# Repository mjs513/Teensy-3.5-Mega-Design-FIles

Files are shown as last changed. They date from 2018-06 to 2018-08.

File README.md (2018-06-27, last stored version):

# Teensy-3.5-Mega-Design-FIles
Kicad/Gerber files for the Teensy 3.5 Breakout Board

See this thread for illustration of board, https://forum.pjrc.com/threads/36244-Teensy-3-5-3-6-Breakout-board-to-test-things-with/page4

Files are provide as is, no guarantee that all connections are 100% correct.  This is a work in progress.  Use at your own risk and check for errors.  

The design was made in KiCad with an export of the Gerber files.

If you find any errors please let me know.  Just to let you know i am currently using this board in my projects.

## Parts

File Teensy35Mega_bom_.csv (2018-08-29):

Component | Description | Part | References | Value | Footprint | Quantity Per PCB | digikey PN
1 |  | BATTERY | BT1 | BATTERY | Keystone_103_1x20mm-CoinCell | 1 | https://www.amazon.com/gp/product/B00NQB2UNU/ref=oh_aui_search_detailpage?ie=UTF8&psc=1
2 | Unpolarized capacitor | C | C2 | C | C_Disc_D3.0mm_W2.0mm_P2.50mm | 1 | UMA1C470MDD
3 | Polarised capacitor | CP | C1 C3 | CP | CP_Radial_D6.3mm_P2.50mm | 2 | 493-5949-ND
4 | DC Barrel Jack | BARREL_JACK | CON1 | BARREL_JACK | BARREL_JACK | 1 | https://www.amazon.com/DIKAVS-Breadboard-friendly-2-1mm-Barrel-Jack/dp/B074LK7G86
5 | Diode, small symbol | D_Small | D1 | D_Small | D_DO-15_P10.16mm_Horizontal | 1 | 1N4001
6 | Connector, single row, 01x02, pin header | CONN_01X02 | J2 | CONN_01X02 | Pin_Header_Straight_1x02_Pitch2.54mm | 1 | Pololu item #: 965, 40 pin breakaway pins
7 | Connector, single row, 01x03, pin header | CONN_01X03 | J1 P4 | CONN_01X03 | Pin_Header_Straight_1x03_Pitch2.54mm | 2
8 | Connector, single row, 01x04, pin header | CONN_01X04 | P9 | CONN_01X04 | Socket_Strip_Straight_1x04_Pitch2.54mm | 1 | S7002-ND
9 | Connector, single row, 01x05, pin header | CONN_01X05 | P7 P16 | CONN_01X05 | Socket_Strip_Straight_1x05_Pitch2.54mm | 2 | S6103-ND
10 | Connector, single row, 01x08, pin header | CONN_01X08 | P1 P2 P12 P13 P14 | CONN_01X08 | Socket_Strip_Straight_1x08_Pitch2.54mm | 5 | PPTC061LFBN-RC
11 | Connector, single row, 01x10, pin header | CONN_01X10 | P3 | CONN_01X10 | Socket_Strip_Straight_1x10_Pitch2.54mm | 1 | PPTC101LFBN-RC
12 | Connector, single row, 01x24, pin header | CONN_01X24 | P5 P11 | CONN_01X24 | Socket_Strip_Straight_1x24_Pitch2.54mm | 2 | PPTC241LFBN-RC
13 | Connector, double row, 02x03, pin header | CONN_02X03 | P15 | CONN_02X03 | Socket_Strip_Straight_2x03_Pitch2.54mm | 1 | S7071-ND | 732-5461-5-ND | Bottom pins for board
14 | Connector, double row, 02x04, pin header | CONN_02X04 | P8 | CONN_02X04 | Socket_Strip_Straight_2x04_Pitch2.54mm | 1 | S7072-ND | 732-5462-5-ND
15 | Connector, double row, 02x05, pin header | CONN_02X05 | P6 | CONN_02X05 | Socket_Strip_Straight_2x05_Pitch2.54mm | 1 | 732-2861-ND | 732-5382-1-ND
16 | Connector, double row, 02x18, pin header | CONN_02X18 | P10 | CONN_02X18 | Socket_Strip_Straight_2x18_Pitch2.54mm | 1 | S7112-ND
17 |  | SW_PUSH | SW2 | PGM | SW_PUSH | 1 | https://www.amazon.com/Uxcell-a11111400ux0130-Momentary-Tactile-Button/dp/B019I11FI2
18 |  | Switch_SPDT_x2 | SW1 | PWR SEL | SW_SPDT | 1 | https://www.amazon.com/dp/B01N7NCW8N
19 |  | SW_PUSH | SW3 | RST | SW_PUSH | 1 | https://www.amazon.com/Uxcell-a11111400ux0130-Momentary-Tactile-Button/dp/B019I11FI2
20 | 1A Low drop-out regulator, Adjustable Output 1.25 - 18.8V, SOT223 | NCP1117ST50T3G_MountingTab | U1 | NCP1117ST50T3G_MountingTab | SOT-223 | 1 | NCP1117ST50T3G
Component Groups: | 20
Component Count: | 28
Fitted Components: | 28
Number of PCBs: | 1
Total components: | 28
Schematic Version:
Schematic Date:
BoM Date: | 6/21/2018 18:24
Schematic Source: | C:/Users/CyberPalin/Documents/Kicad Test/Teensy35Mega/Teensy35Mega.sch
KiCad Version: | Eeschema 4.0.6

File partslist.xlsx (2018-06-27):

Index | Quantity | Part Number | Manufacturer Part Number | Description | Customer Reference | Backorder | Unit Price | Extended Price
1 | 1 | ED10674-ND | 827-22-010-10-004101 | CONN, SPRING LOADED HEADER |  | 0 | 8.49 | $8.49
2 | 1 | ED10673-ND | 827-22-006-10-004101 | CONN, SPRING LOADED HEADER |  | 0 | 6.46 | $6.46
3 | 1 | ED10666-ND | 827-22-008-10-001101 | CONN, SPRING LOADED HEADER |  | 0 | 6.95 | $6.95
 |  |  |  |  |  |  | Subtotal | $21.90
Index | Quantity | Part Number | Manufacturer Part Number | Description | Customer Reference | Backorder | Unit Price | Extended Price
1 | 25 | S7004-ND | PPTC061LFBN-RC | CONN HEADER FEMALE 6POS .1" TIN |  | 0 | 0.4924 | $12.31
2 | 25 | S7006-ND | PPTC081LFBN-RC | CONN HEADER FEMALE 8POS .1" TIN |  | 0 | 0.6188 | $15.47
3 | 100 | 497-3707-1-ND | BAT60JFILM | DIODE SCHOTTKY 10V 3A SOD323 |  | 0 | 0.1813 | $18.13
4 | 25 | S7008-ND | PPTC101LFBN-RC | CONN HEADER FEMALE 10POS.1" TIN |  | 0 | 0.6252 | $15.63
 |  |  |  |  |  |  | Subtotal | $61.54
Index | Quantity | Part Number | Manufacturer Part Number | Description | Customer Reference | Backorder | Unit Price | Extended Price | 168297602
1 | 25 | 493-5949-ND | UMA1C470MDD | CAP ALUM 47UF 20% 16V RADIAL |  | 0 | 0.182 | $4.55
2 | 10 | NCP1117ST50T3GOSCT-ND | NCP1117ST50T3G | IC REG LINEAR 5V 1A SOT223 |  | 0 | 0.43 | $4.30
 |  |  |  |  |  |  | Subtotal | $8.85
Index | Quantity | Part Number | Manufacturer Part Number | Description | Customer Reference | Backorder | Unit Price | Extended Price | 167904051
1 | 10 | NCP1117ST50T3GOSCT-ND | NCP1117ST50T3G | IC REG LINEAR 5V 1A SOT223 |  | 0 | 0.43 | $4.30
2 | 25 | 493-5949-ND | UMA1C470MDD | CAP ALUM 47UF 20% 16V RADIAL |  | 0 | 0.1388 | $3.47
 |  |  |  |  |  |  | Subtotal | $7.77
Index | Quantity | Part Number | Manufacturer Part Number | Description | Customer Reference | Backorder | Unit Price | Extended Price | 162680809
1 | 6 | WM17458-ND | 15-91-0080 | CONN HEADER 8POS .100" VERT 15AU |  | 0 | 0.74 | $4.44
2 | 6 | WM17459-ND | 15910100 | CONN HEADER 10POS .100" STR 15AU |  | 0 | 1.22 | $7.32
3 | 6 | WM17457-ND | 15910060 | CONN HEADER 6POS .100" VERT 15AU |  | 0 | 0.57 | $3.42
 |  |  |  |  |  |  | Subtotal | $15.18
Index | Quantity | Part Number | Manufacturer Part Number | Description | Customer Reference | Backorder | Unit Price | Extended Price
1 | 4 | 732-5382-1-ND | 61031021121 | CONN HEADER VERT DUAL 10POS 2.54 |  | 0 | 1.84 | $7.36
2 | 4 | 732-5461-5-ND | 61000621121 | CONN HEADER VERT DUAL 6POS 2.54 |  | 0 | 0.94 | $3.76
3 | 4 | 732-5462-5-ND | 61000821121 | CONN HEADER VERT DUAL 8POS 2.54 |  | 0 | 1.64 | $6.56
 |  |  |  |  |  |  | Subtotal | $17.68
Index | Quantity | Part Number | Manufacturer Part Number | Description | Customer Reference | Backorder | Unit Price | Extended Price | 161125295
1 | 4 | 732-5382-1-ND | 61031021121 | CONN HEADER VERT DUAL 10POS 2.54 |  | 0 | 1.84 | $7.36
2 | 4 | 732-5461-5-ND | 61000621121 | CONN HEADER VERT DUAL 6POS 2.54 |  | 0 | 0.94 | $3.76
3 | 4 | 732-5462-5-ND | 61000821121 | CONN HEADER VERT DUAL 8POS 2.54 |  | 0 | 1.64 | $6.56
 |  |  |  |  |  |  | Subtotal | $17.68
Index | Quantity | Part Number | Manufacturer Part Number | Description | Customer Reference | Backorder | Unit Price | Extended Price | 161125295
1 | 4 | 732-5382-1-ND | 61031021121 | CONN HEADER VERT DUAL 10POS 2.54 |  | 0 | 1.84 | $7.36
2 | 4 | 732-5461-5-ND | 61000621121 | CONN HEADER VERT DUAL 6POS 2.54 |  | 0 | 0.94 | $3.76
3 | 4 | 732-5462-5-ND | 61000821121 | CONN HEADER VERT DUAL 8POS 2.54 |  | 0 | 1.64 | $6.56
 |  |  |  |  |  |  | Subtotal | $17.68
Index | Quantity | Part Number | Manufacturer Part Number | Description | Customer Reference | Backorder | Unit Price | Extended Price | 160228521
1 | 4 | WM17458-ND | 15-91-0080 | CONN HEADER 8POS .100" VERT 15AU |  | 0 | 0.74 | $2.96
2 | 4 | WM17459-ND | 15910100 | CONN HEADER 10POS .100" STR 15AU |  | 0 | 1.22 | $4.88
3 | 4 | WM17461-ND | 15910140 | CONN HEADER 14POS .100" STR 15AU |  | 0 | 1.39 | $5.56
 |  |  |  |  |  |  | Subtotal | $13.40
 |  |  |  | 100 Pcs 6 x 6mm x 4.3mm Panel PCB Momentary Tactile Tact Push Button Switch DIP
 |  |  |  | 25 Pcs On-Off SPDT Vertical Slide Switch PCB Panel 3 Pin 1P2T 4mm SS12DOOG4
 |  |  |  | https://www.amazon.com/gp/product/B00NQB2UNU/ref=oh_aui_search_detailpage?ie=UTF8&psc=1
 |  |  |  | uxcell 10Pcs Coin Cell Button Battery Holder Socket for CR2016/2025/2032
 |  |  |  | https://www.amazon.com/DIKAVS-Breadboard-friendly-2-1mm-Barrel-Jack/dp/B074LK7G86
 |  |  |  | DIKAVS Breadboard-friendly 2.1mm DC Barrel Jack (Pack of 10)
 |  |  |  | https://www.amazon.com/Glarks-Breadboard-Connectors-Assortment-Electronic/dp/B07C188YGC?s=electronics&rps=1
 |  |  |  | Glarks 248Pcs 40 Pin Breakaway Pin Headers and 2.54mm Circuit Board Jumper Caps with Breadboard Dupont Jumper Wire Ribbon Cables Connectors Assortment Set for Electronic Technology Arduino DIY

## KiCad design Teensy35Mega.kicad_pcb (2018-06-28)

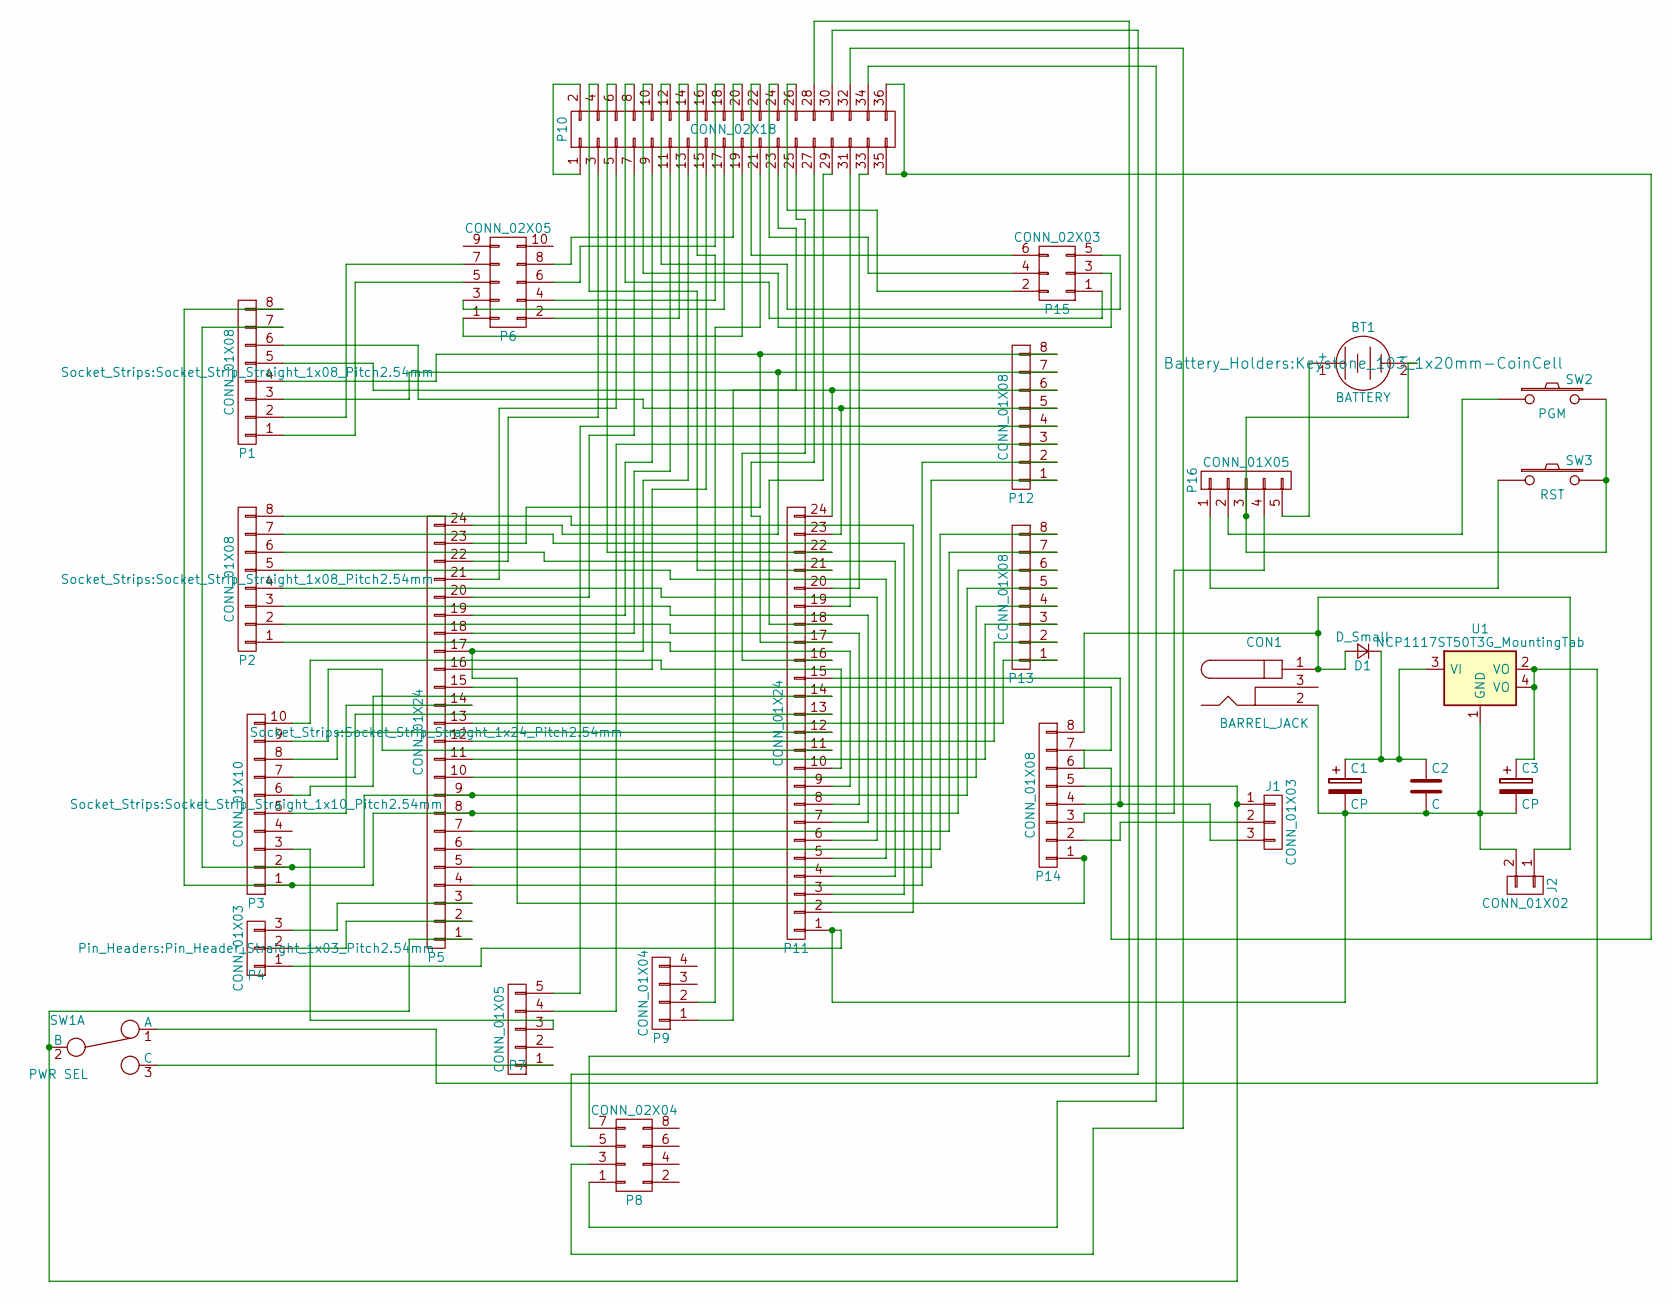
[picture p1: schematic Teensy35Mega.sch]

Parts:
BT1: BATTERY; Keystone_103_1x20mm-CoinCell
C1, C3: CP; CP_Radial_D6.3mm_P2.50mm
C2: C; C_Disc_D3.0mm_W2.0mm_P2.50mm
CON1: BARREL_JACK
D1: D_Small; D_DO-15_P10.16mm_Horizontal
J1: CONN_01X03; Pin_Header_Straight_1x03_Pitch2.54mm
J2: CONN_01X02; Pin_Header_Straight_1x02_Pitch2.54mm
P1, P2, P12, P13, P14: CONN_01X08; Socket_Strip_Straight_1x08_Pitch2.54mm
P3: CONN_01X10; Socket_Strip_Straight_1x10_Pitch2.54mm
P4: CONN_01X03; Pin_Header_Straight_1x03_Pitch2.54mm
P5, P11: CONN_01X24; Socket_Strip_Straight_1x24_Pitch2.54mm
P6: CONN_02X05; Socket_Strip_Straight_2x05_Pitch2.54mm
P7, P16: CONN_01X05; Socket_Strip_Straight_1x05_Pitch2.54mm
P8: CONN_02X04; Socket_Strip_Straight_2x04_Pitch2.54mm
P9: CONN_01X04; Socket_Strip_Straight_1x04_Pitch2.54mm
P10: CONN_02X18; Socket_Strip_Straight_2x18_Pitch2.54mm
P15: CONN_02X03; Socket_Strip_Straight_2x03_Pitch2.54mm
SW1: PWR SEL; SW_SPDT
SW2: PGM; SW_PUSH
SW3: RST; SW_PUSH
U1: NCP1117ST50T3G_MountingTab; SOT-223

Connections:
unnamed: BT1.1 (+), P16.5
unnamed: BT1.2 (-), P16.3, SW2.2, SW3.2
unnamed: C1.1, C2.1, D1.1 (K), U1.3 (VI)
unnamed: C1.2, C2.2, C3.2, CON1.2, J2.2, P4.1, P11.1, U1.1 (GND)
unnamed: C3.1, SW1.1 (A), U1.2 (VO), U1.4 (VO)
unnamed: CON1.1, D1.2 (A), J2.1, P14.8
unnamed: J1.1, P5.1, P14.5, SW1.2 (B)
unnamed: J1.2, P14.2
unnamed: J1.3, P11.15, P14.4
unnamed: P1.1, P6.5
unnamed: P1.2, P6.7
unnamed: P1.3, P5.24, P12.7
unnamed: P1.4, P5.23, P12.8
unnamed: P1.5, P11.24, P12.6
unnamed: P1.6, P11.23, P12.5
unnamed: P1.7, P3.2, P5.9, P13.5
unnamed: P1.8, P3.1, P5.8, P13.6
unnamed: P3.3, P7.3
unnamed: P3.5, P5.14
unnamed: P4.2, P5.2
unnamed: P4.3, P5.3
unnamed: P7.1, SW1.3 (C)
unnamed: P10.1, P10.2
unnamed: P5.22, P10.3
unnamed: P10.4, P11.21
unnamed: P5.21, P10.5
unnamed: P10.6, P11.22
unnamed: P5.20, P10.7
unnamed: P10.8, P15.1
unnamed: P5.19, P10.9
unnamed: P10.10, P15.3
unnamed: P5.18, P10.11
unnamed: P10.12, P15.5
unnamed: P5.17, P10.13, P14.1
unnamed: P6.2, P10.14
unnamed: P5.16, P10.15
unnamed: P6.4, P10.16
unnamed: P6.3, P10.17
unnamed: P6.6, P10.18
unnamed: P6.1, P10.19
unnamed: P6.8, P10.20
unnamed: P9.2, P10.21
unnamed: P10.22, P15.6
unnamed: P9.1, P10.23
unnamed: P10.24, P15.4
unnamed: P10.25, P11.16
unnamed: P10.26, P15.2
unnamed: P10.27, P11.17
unnamed: P8.7, P10.28
unnamed: P10.29, P11.18
unnamed: P8.5, P10.30
unnamed: P10.31, P11.19
unnamed: P8.3, P10.32
unnamed: P10.33, P11.20
unnamed: P8.1, P10.34
unnamed: P5.15, P10.35, P10.36, P14.6, P14.7
unnamed: P2.8, P11.2
unnamed: P2.7, P11.3
unnamed: P2.6, P11.4
unnamed: P2.5, P11.5
unnamed: P2.4, P11.6
unnamed: P2.3, P11.7
unnamed: P2.2, P11.8
unnamed: P2.1, P11.9
unnamed: P3.10, P11.10
unnamed: P3.9, P11.11
unnamed: P3.8, P11.12
unnamed: P3.7, P11.13
unnamed: P3.6, P11.14
unnamed: P5.5, P12.1
unnamed: P5.4, P12.2
unnamed: P7.4, P12.3
unnamed: P7.5, P12.4
unnamed: P5.13, P13.1
unnamed: P5.12, P13.2
unnamed: P5.11, P13.3
unnamed: P5.10, P13.4
unnamed: P5.7, P13.7
unnamed: P5.6, P13.8
unnamed: P14.3, P16.4
unnamed: P16.1, SW3.1
unnamed: P16.2, SW2.1

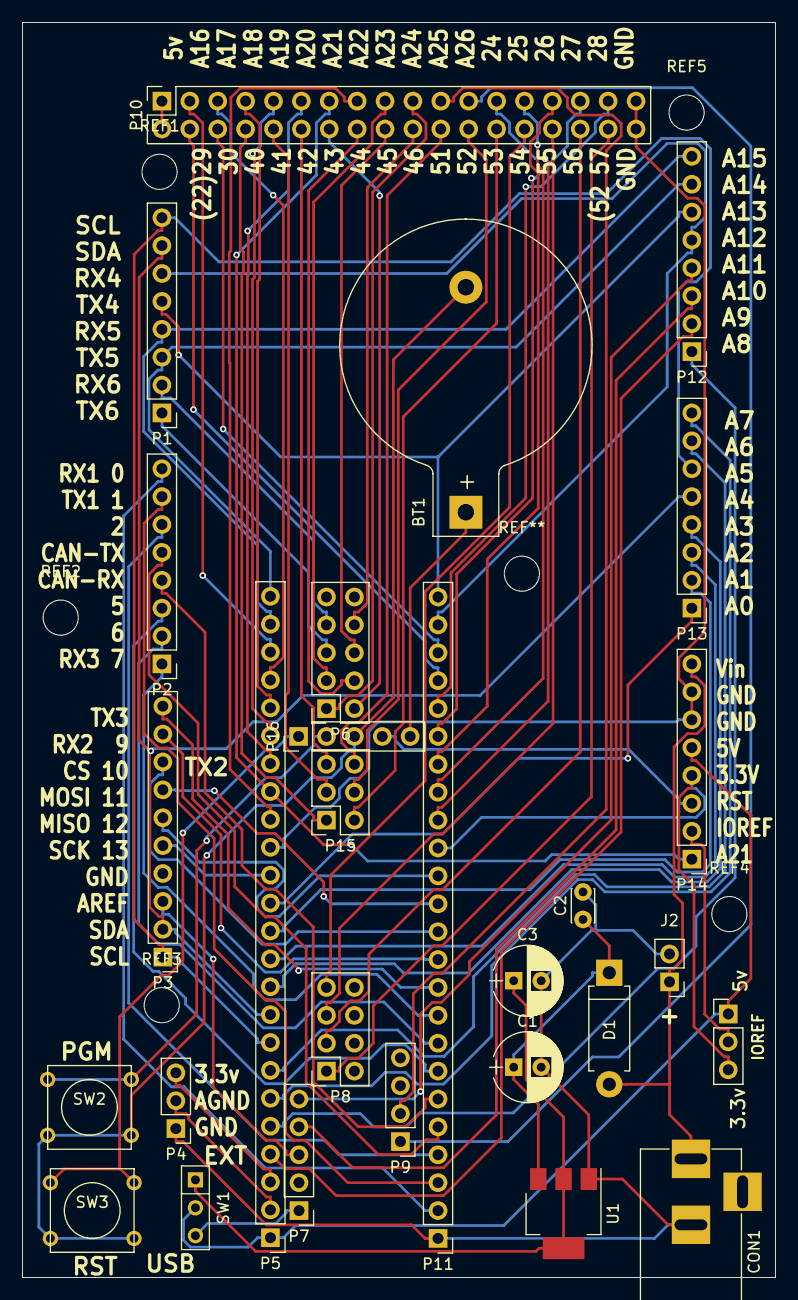
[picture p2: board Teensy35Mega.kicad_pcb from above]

Board: 2 copper layers, 68.6 x 114.3 mm, 33 parts (0 on the bottom side), 82 nets.

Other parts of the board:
REF1, REF2, REF3, REF4, REF5: MountingHole_3.2mm_M3_ISO14580_Pad; MountingHole_3.2mm_M3

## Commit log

2018-06-27 Initial add of files and partial BOM
    [Teensy35Mega-B.Adhes.gbr, Teensy35Mega-B.CrtYd.gbr, Teensy35Mega-B.Cu.gbr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]
2018-06-28 Updated P8 connections & Layout
    Updated P8 connections. per @boelle on PRJC Forum
    [Teensy35Mega-B.Adhes.gbr, Teensy35Mega-B.CrtYd.gbr, Teensy35Mega-B.Cu.gbr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]
2018-08-29 Updated BOM
    [Teensy35Mega_bom_.csv]
